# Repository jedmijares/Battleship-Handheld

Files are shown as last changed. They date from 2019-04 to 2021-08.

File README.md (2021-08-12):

# Battleship Handheld

This project was created as the final project for EE 287 (Intro to Embedded Systems), by Jed Mijares and Jacob Culler.

## YouTube Video Demo

[Watch Here](https://www.youtube.com/watch?v=jDSAx5fQOlo)

## Compiling

Battleship was written and built with Keil uVision5.

## Description and Operation

If you are not familiar with the board game Battleship, you can read about it [here.](https://en.wikipedia.org/wiki/Battleship_(game))

We implemented the game on a Texas Intrument Tiva C Series Launchpad (EK-TM4C123GXL). When booted up, a short credit message is displayed on a Nokia 5110 screen. The user may press any button to proceed to the game board. The time at which they press the button is used as a seed for a randomization function, and we use this function to randomly place a length 2, length 3, and length 4 ship on an 8x8 grid. Next, the player will use the D-pad to navigate and the select button to fire at the selected square. The game will display an X for each square with a targeted ship and a 0 for each targeted empty square. The game is completed when the player has sunken each ship. At this point, a win screen is displayed, showing the number of shots the player had to fire to complete the game. They player can hit any button to reset the game and play again.

## Explanation of Design Choices

We were attracted to using the Nokia 5110 screen, as Dr. Valvano had provided a library for it as part of his online Embedded Systems course, which we referred to often throughout this semester. We settled upon implementing Battleship after discovering that the Nokia screen flickered a lot when sprites were quickly moved across it.

We used an 8x8 grid for the board as it fit nicely on the Nokia's 48x84 pixel screen. This left enough space for 6 rows of 4 characters, which we used to display the number of shots fired, the number of successful hits, and which ships had been successfully sunk. In software, the board is a 2 dimensional array of _Square_ structs, which keep track of whether a tile has been shot and an ID for the ship that resides there (or lack thereof).

The PCB features several extraneous components. These include a terminal block for breaking out UART pins, an extra unused button, and several rows of jumper pins. These serve no purpose in the current design, but were added in case we decided to implement a feature that would require them.

## Parts List

* TM4C123G LaunchPad Evaluation Kit
* Nokia 5110 Screen Breakout Board
* Piezo Buzzer
* 10kR Resistor (5)
* Pushbutton Switch (5)

### Optional Components

* 330R Resistor (may be used to enable the backlight)
* 4-pin terminal block (breaks out the UART pins, which currently are not used)
* 10kR Resistor (for extra button that currently serves no purpose)
* Pushbutton Switch (extra button that currently serves no purpose)

## Flow Diagram

[Code Flow Diagram](https://github.com/jedmijares/EE-287-Final-Project/blob/master/Media/Code%20Block%20Diagram.pdf)

## Explanation of Major Components

The Tiva board is crucial to the project, and controls all the other components and handles the processing for the game itself.

The Tiva communicates with the Nokia 5110 screen serially and uses it to communicate all visual output.

A piezo buzzer is also implemented. Whenever a button is pressed, the SysTick timer is used to oscillate the buzzer pin for a specified number of milliseconds.

The PCB was designed in Autodesk EAGLE. Relevant design files are in the EAGLE folder.

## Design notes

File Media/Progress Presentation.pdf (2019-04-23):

# BATTLESHIP GAME

Jed Mijares

Jacob Culler

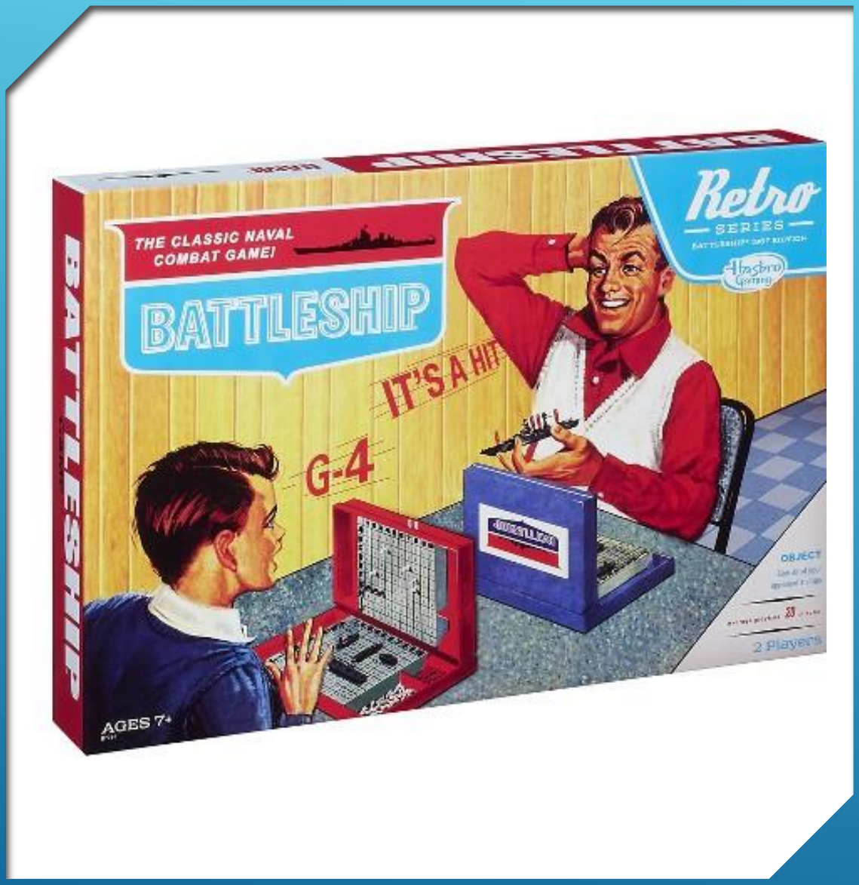
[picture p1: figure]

# INTRODUCTION / PROJECT DESCRIPTION

We are making a handheld
game that lets you play the board game battleship

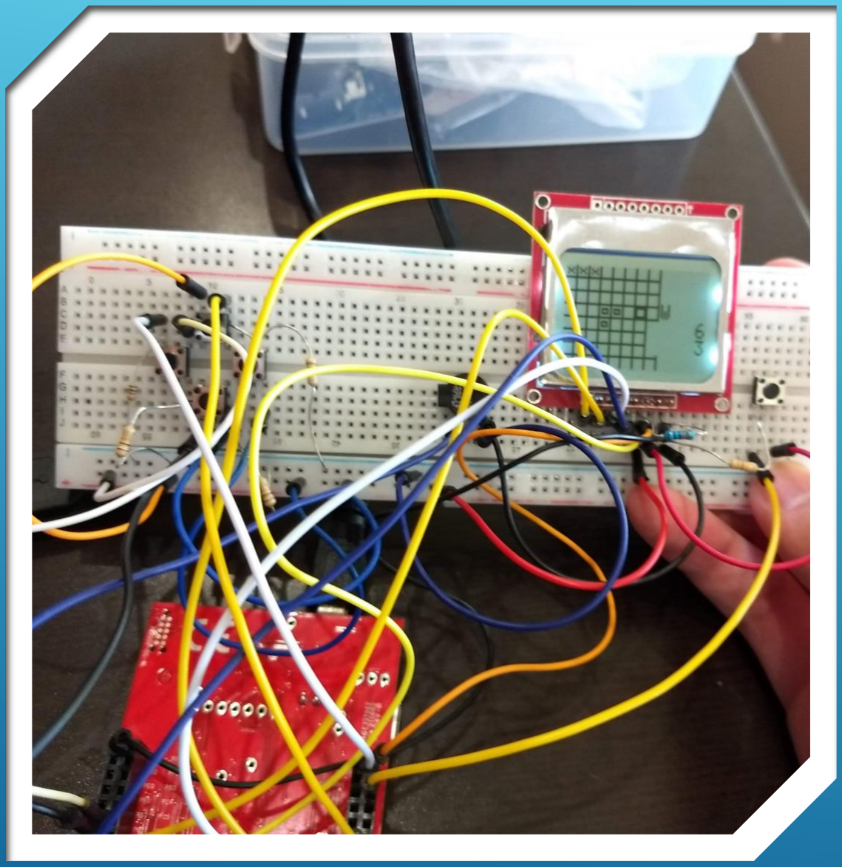
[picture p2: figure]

# CURRENT PROGRESS

- LCD Communication
- Button Integration
- Sound Output
- Basic Game Logic

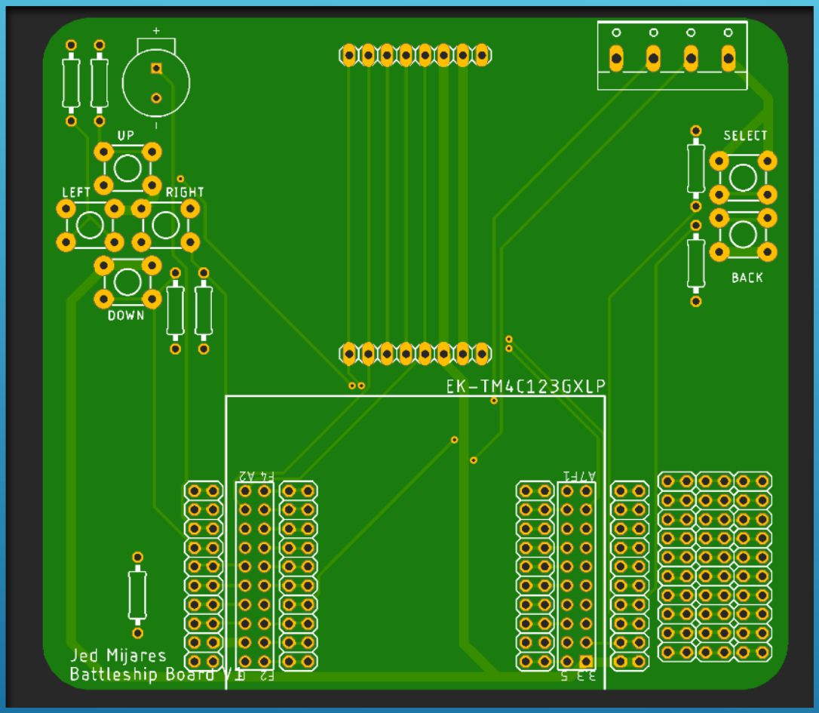
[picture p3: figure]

# REMAINING WORK

- Implement randomization
- Clean up code/formatting
- Produce video
- Print/assemble PCB
- Online scoreboard
- UART Multiplayer/computer player
- Create frame

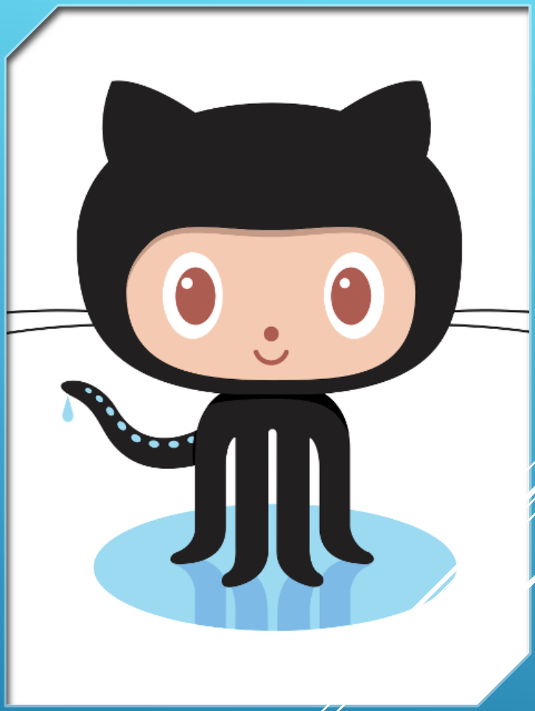
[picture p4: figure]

# DIFFICULTIES

- Learning how to use GitHub collaboratively
- LCD blur prevented us from making a more “actiony” game
- Discovered we could only print bitmaps of an even width

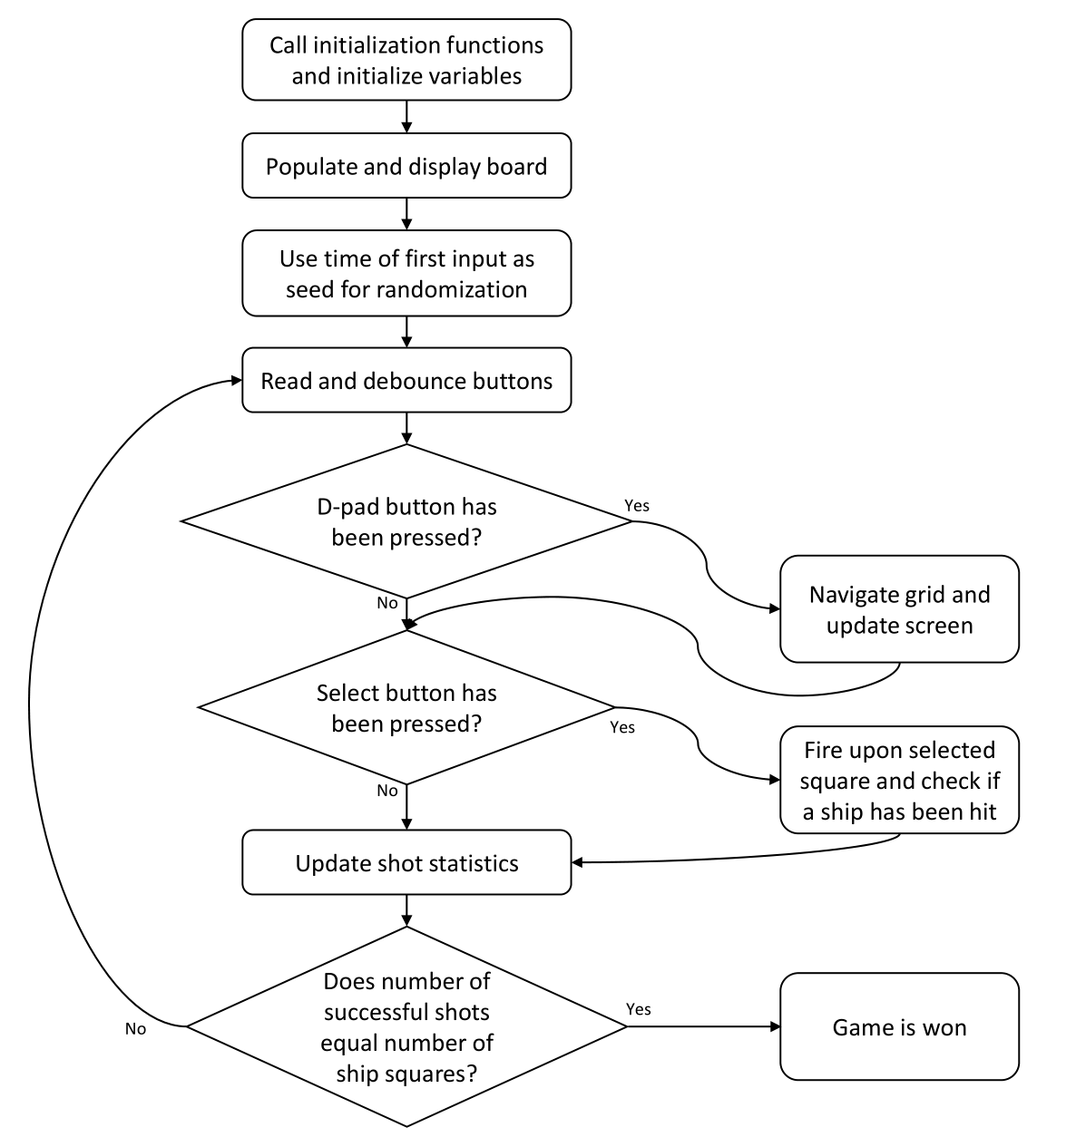
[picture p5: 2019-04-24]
Media/CodeBlockDiagram.PNG

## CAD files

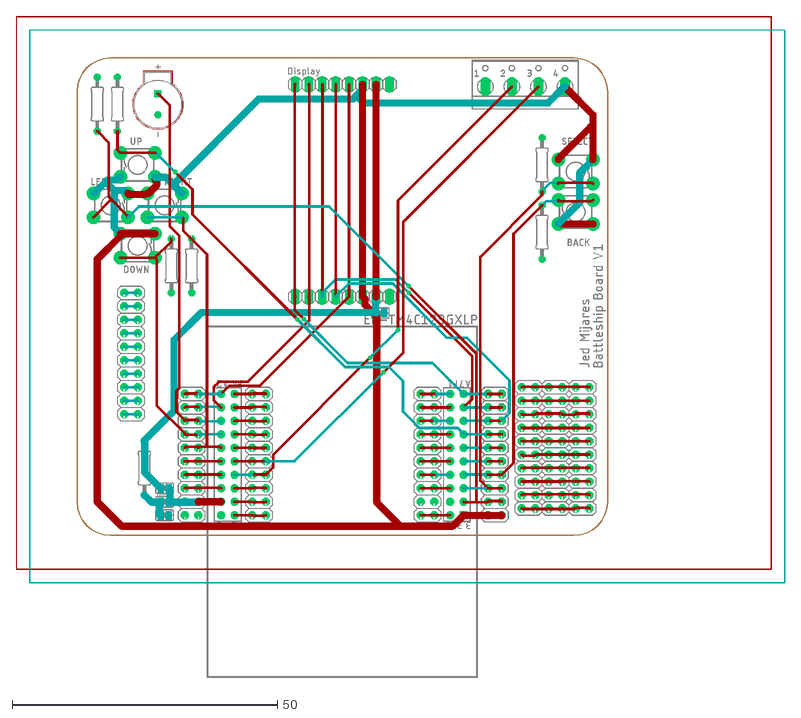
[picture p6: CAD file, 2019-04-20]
EAGLE/battleship.dxf
144.9 x 124.7

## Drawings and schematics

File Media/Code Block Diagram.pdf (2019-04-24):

EE 287

### Battleship Block Diagram

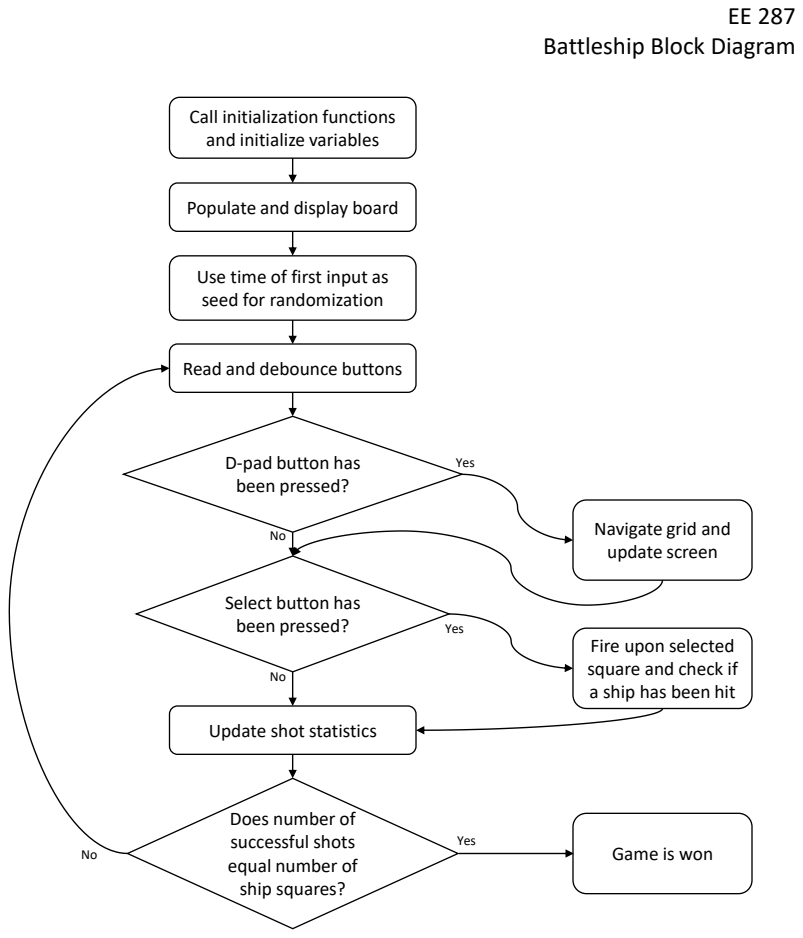
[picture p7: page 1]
Yes

Call initialization functions
and initialize variables

Populate and display board

Use time of first input as
seed for randomization

Read and debounce buttons

D-pad button has
been pressed?

Navigate grid and
update screen

Select button has

Fire upon selected
square and check if
a ship has been hit

Update shot statistics

Does number of
successful shots
equal number of
ship squares?

Game is won

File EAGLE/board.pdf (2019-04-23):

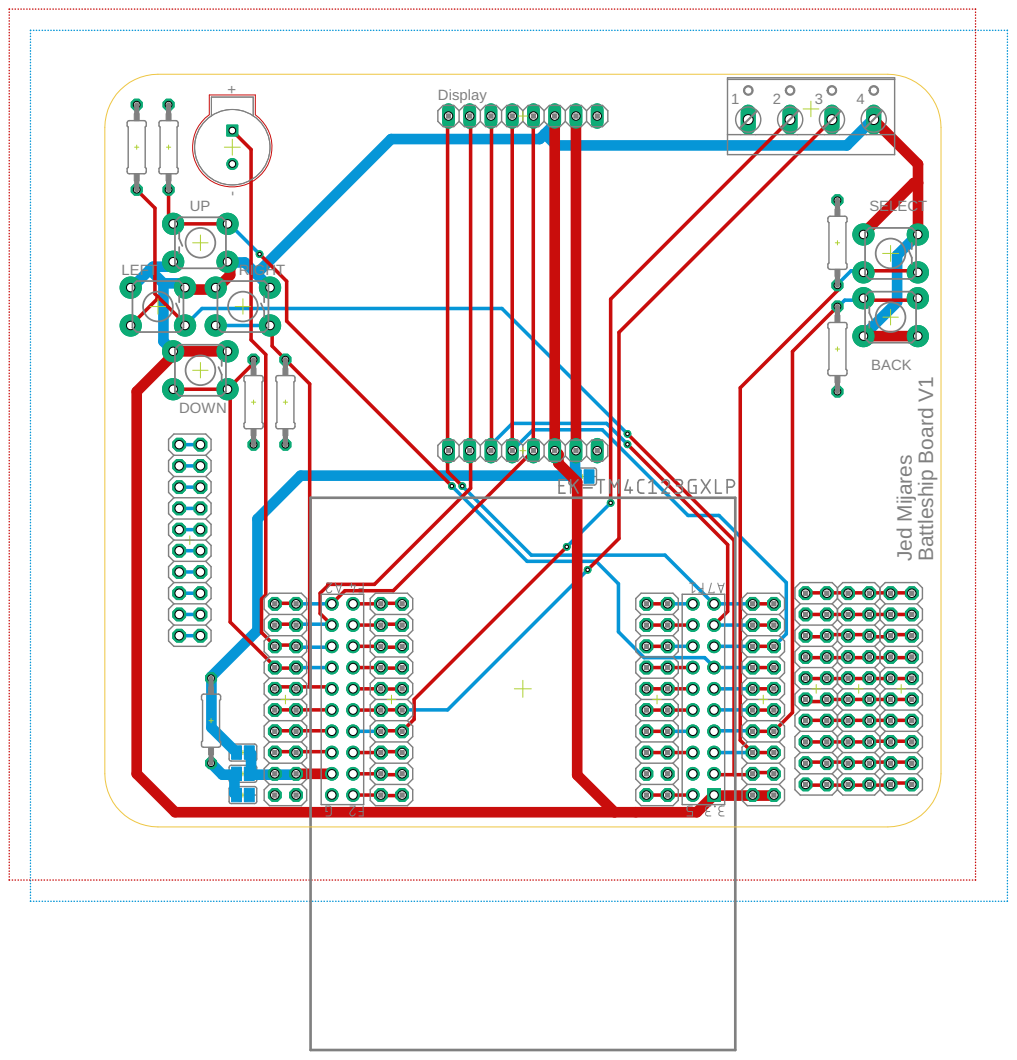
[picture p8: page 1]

Jed Mijares Battleship Board V1 + - 1 2 3 4 LEFT RIGHT DOWN UP SELECT BACK Display

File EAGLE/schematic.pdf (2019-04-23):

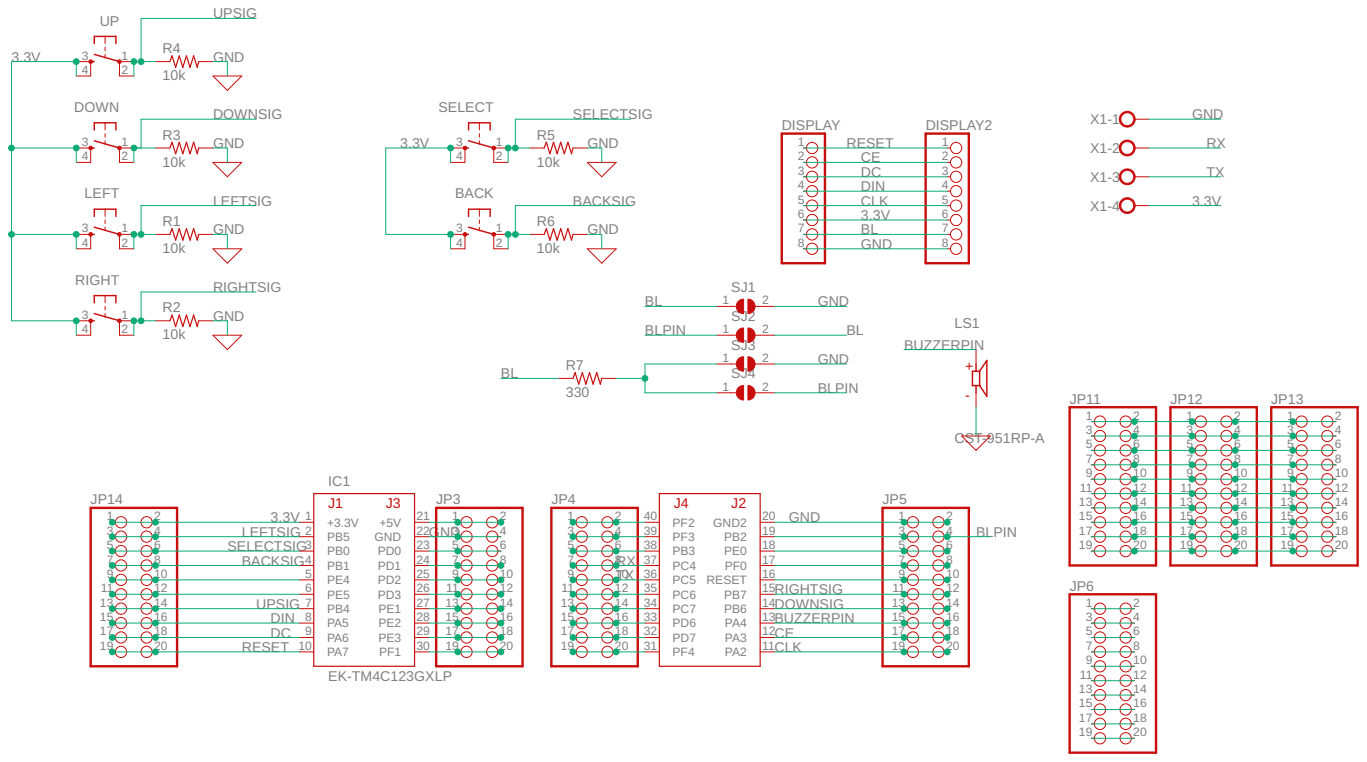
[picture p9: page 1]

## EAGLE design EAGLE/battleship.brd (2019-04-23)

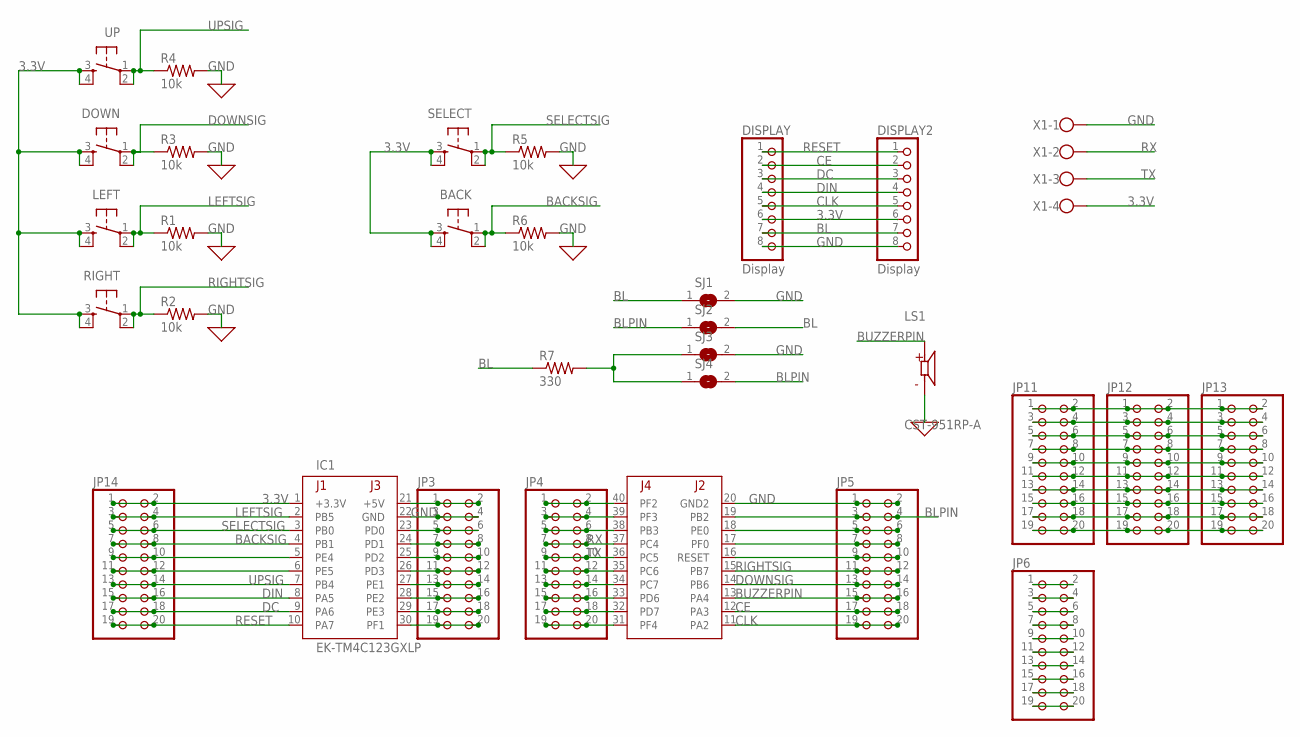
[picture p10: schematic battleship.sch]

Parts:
BACK: TAC_SWITCHPTH; TACTILE-PTH
DISPLAY, DISPLAY2: Display; 1X08
DOWN: TAC_SWITCHPTH; TACTILE-PTH
IC1: EK-TM4C123GXLP; TM4C123LAUNCHPAD
JP3, JP4, JP5, JP6, JP11, JP12, JP13, JP14: PINHD-2X10; 2X10
LEFT: TAC_SWITCHPTH; TACTILE-PTH
LS1: CST-951RP-A; CUI_CST-951RP-A
R1, R2, R3, R4, R5, R6: 10k; 0207/10
R7: 330; 0207/10
RIGHT: TAC_SWITCHPTH; TACTILE-PTH
SELECT: TAC_SWITCHPTH; TACTILE-PTH
SJ1, SJ2, SJ3, SJ4: SJ
UP: TAC_SWITCHPTH; TACTILE-PTH
X1: W237-4

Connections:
3.3V: BACK.3, BACK.4, DISPLAY.6, DISPLAY2.6, DOWN.3, DOWN.4, IC1.1 (+3.3V), JP14.1, JP14.2, LEFT.3, LEFT.4, RIGHT.3, RIGHT.4, SELECT.3, SELECT.4, UP.3, UP.4, X1.4
BACKSIG: BACK.1, BACK.2, IC1.4 (PB1), JP14.7, JP14.8, R6.1
BL: DISPLAY.7, DISPLAY2.7, R7.1, SJ1.1, SJ2.2
BLPIN: IC1.19 (PB2), JP5.3, JP5.4, SJ2.1, SJ4.2
BUZZERPIN: IC1.13 (PA4), JP5.15, JP5.16, LS1.P
CE: DISPLAY.2, DISPLAY2.2, IC1.12 (PA3), JP5.17, JP5.18
CLK: DISPLAY.5, DISPLAY2.5, IC1.11 (PA2), JP5.19, JP5.20
DC: DISPLAY.3, DISPLAY2.3, IC1.9 (PA6), JP14.17, JP14.18
DIN: DISPLAY.4, DISPLAY2.4, IC1.8 (PA5), JP14.15, JP14.16
DOWNSIG: DOWN.1, DOWN.2, IC1.14 (PB6), JP5.13, JP5.14, R3.1
GND: DISPLAY.8, DISPLAY2.8, IC1.20 (GND2), IC1.22 (GND), JP3.3, JP3.4, JP5.1, JP5.2, LS1.M, R1.2, R2.2, R3.2, R4.2, R5.2, R6.2, SJ1.2, SJ3.2, X1.1
LEFTSIG: IC1.2 (PB5), JP14.3, JP14.4, LEFT.1, LEFT.2, R1.1
unnamed: JP6.1, JP6.2
unnamed: JP6.3, JP6.4
unnamed: JP6.5, JP6.6
unnamed: JP6.7, JP6.8
unnamed: JP6.9, JP6.10
unnamed: R7.2, SJ3.1, SJ4.1
unnamed: JP6.11, JP6.12
unnamed: JP6.13, JP6.14
unnamed: JP6.15, JP6.16
unnamed: JP6.19, JP6.20
unnamed: JP6.17, JP6.18
unnamed: IC1.5 (PE4), JP14.9, JP14.10
unnamed: IC1.21 (+5V), JP3.1, JP3.2
unnamed: IC1.23 (PD0), JP3.5, JP3.6
unnamed: IC1.24 (PD1), JP3.7, JP3.8
unnamed: IC1.16 (RESET), JP5.9, JP5.10
unnamed: IC1.17 (PF0), JP5.7, JP5.8
unnamed: IC1.18 (PE0), JP5.5, JP5.6
unnamed: IC1.28 (PE2), JP3.15, JP3.16
unnamed: IC1.29 (PE3), JP3.17, JP3.18
unnamed: IC1.30 (PF1), JP3.19, JP3.20
unnamed: IC1.31 (PF4), JP4.19, JP4.20
unnamed: IC1.32 (PD7), JP4.17, JP4.18
unnamed: IC1.26 (PD3), JP3.11, JP3.12
unnamed: IC1.25 (PD2), JP3.9, JP3.10
unnamed: JP11.3, JP11.4, JP12.3, JP12.4, JP13.3, JP13.4
unnamed: JP11.7, JP11.8, JP12.7, JP12.8, JP13.7, JP13.8
unnamed: IC1.33 (PD6), JP4.15, JP4.16
unnamed: IC1.34 (PC7), JP4.13, JP4.14
unnamed: JP11.11, JP11.12, JP12.11, JP12.12, JP13.11, JP13.12
unnamed: IC1.35 (PC6), JP4.11, JP4.12
unnamed: JP11.15, JP11.16, JP12.15, JP12.16, JP13.15, JP13.16
unnamed: JP11.17, JP11.18, JP12.17, JP12.18, JP13.17, JP13.18
unnamed: JP11.19, JP11.20, JP12.19, JP12.20, JP13.19, JP13.20
unnamed: IC1.38 (PB3), JP4.5, JP4.6
unnamed: IC1.39 (PF3), JP4.3, JP4.4
unnamed: IC1.40 (PF2), JP4.1, JP4.2
unnamed: IC1.6 (PE5), JP14.11, JP14.12
unnamed: IC1.27 (PE1), JP3.13, JP3.14
unnamed: JP11.1, JP11.2, JP12.1, JP12.2, JP13.1, JP13.2
unnamed: JP11.5, JP11.6, JP12.5, JP12.6, JP13.5, JP13.6
unnamed: JP11.9, JP11.10, JP12.9, JP12.10, JP13.9, JP13.10
unnamed: JP11.13, JP11.14, JP12.13, JP12.14, JP13.13, JP13.14
RESET: DISPLAY.1, DISPLAY2.1, IC1.10 (PA7), JP14.19, JP14.20
RIGHTSIG: IC1.15 (PB7), JP5.11, JP5.12, R2.1, RIGHT.1, RIGHT.2
RX: IC1.37 (PC4), JP4.7, JP4.8, X1.2
SELECTSIG: IC1.3 (PB0), JP14.5, JP14.6, R5.1, SELECT.1, SELECT.2
TX: IC1.36 (PC5), JP4.9, JP4.10, X1.3
UPSIG: IC1.7 (PB4), JP14.13, JP14.14, R4.1, UP.1, UP.2

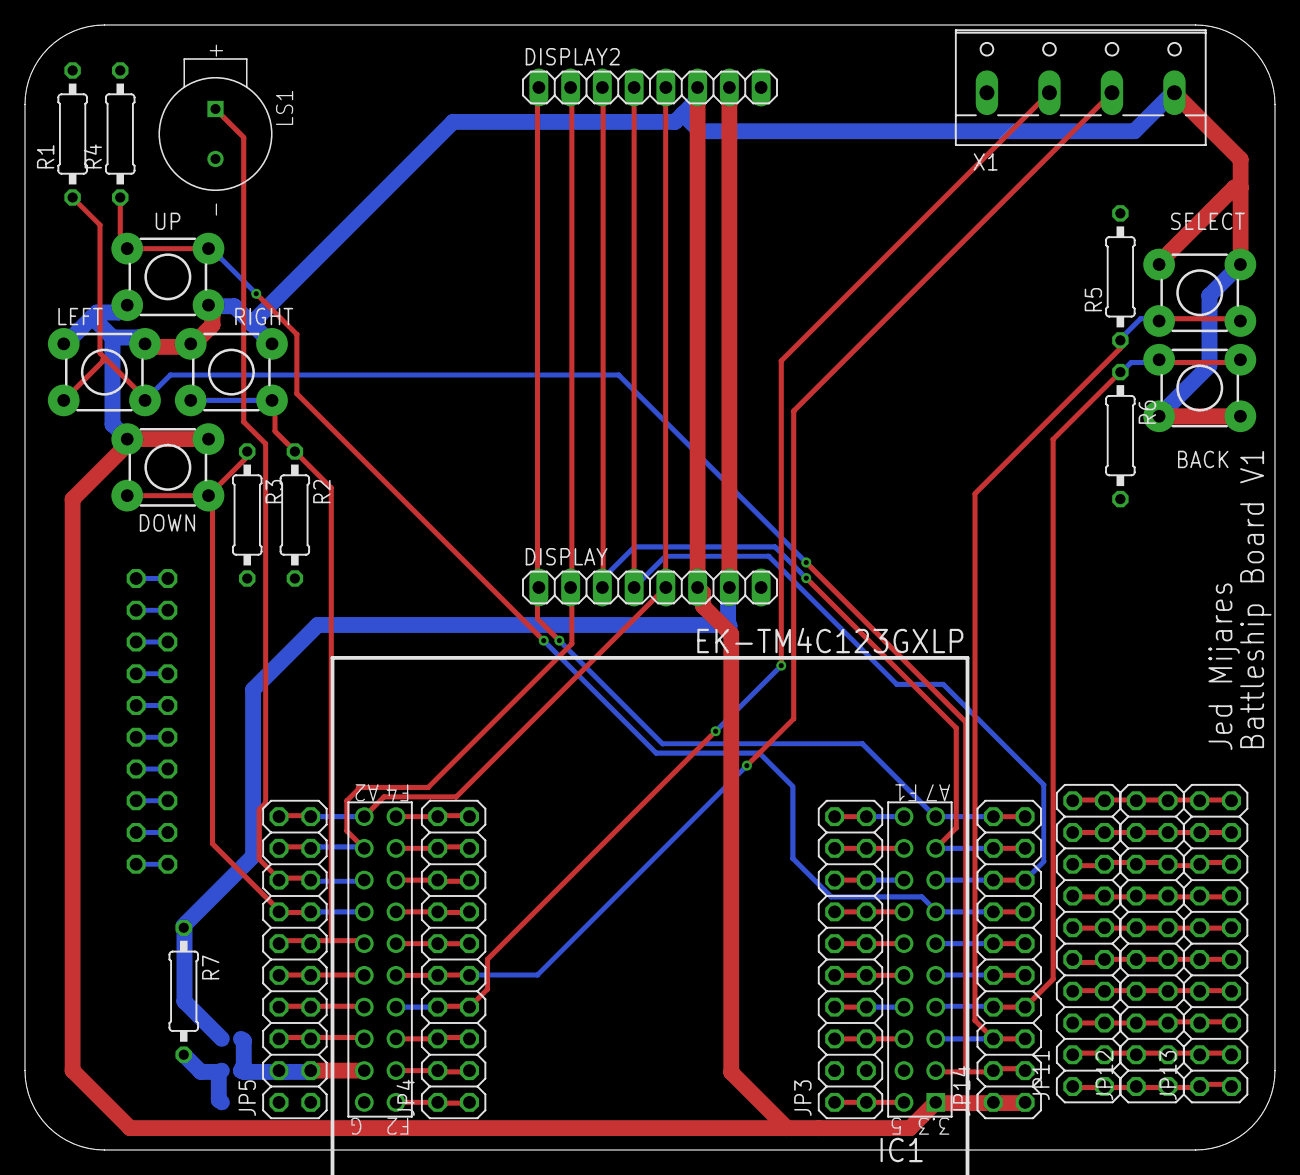
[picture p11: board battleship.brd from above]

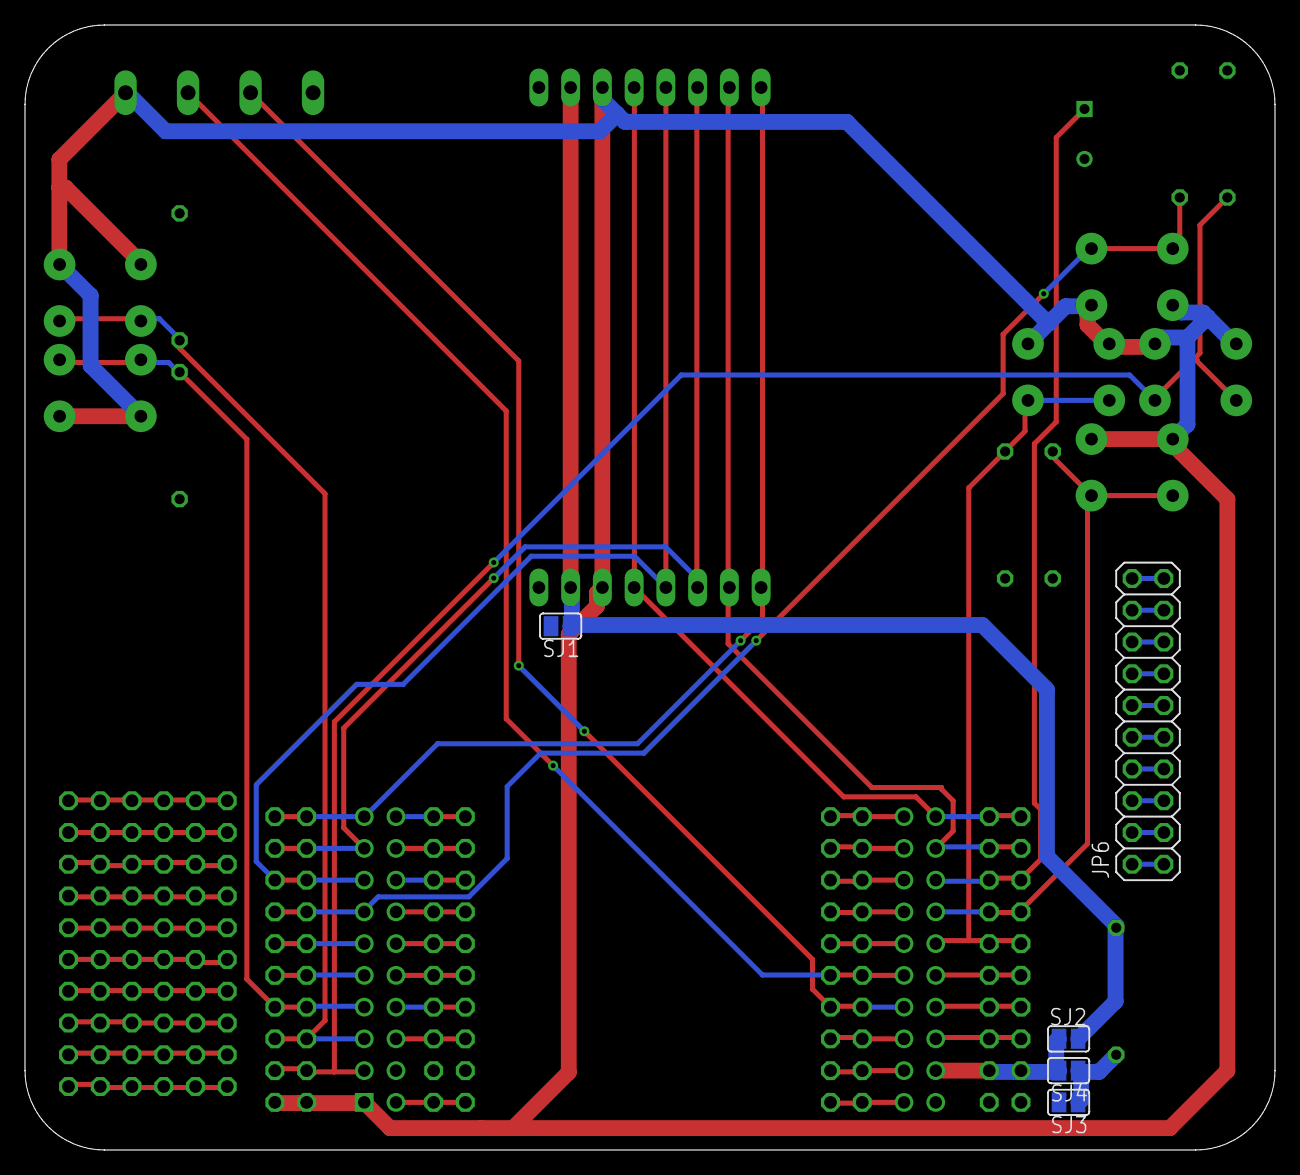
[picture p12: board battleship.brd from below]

Board: 2 copper layers, 100.0 x 90.0 mm, 30 parts (5 on the bottom side), 61 nets.

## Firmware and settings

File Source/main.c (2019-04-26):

// main file for EE 287 final project
// By Jed Mijares and Jacob Culler

#include "Nokia5110.h"
#include "PLL.h"
#include "Ports.h"
#include "SysTick.h"
#include "tm4c123gh6pm.h"
#include "structs.h"
#include "printMatrix.h"
#include "random.h"
#include <stdbool.h>

struct Square board[8][8];
short xCursor = 0;
short yCursor = 0;


void checkBounds(short *x , short *y){
	if(*x > 7)
		*x = 7;
	if(*x < 0)
		*x = 0;
	if(*y < 0)
		*y = 0;
	if(*y > 7)
		*y = 7;
}

void fire(){
	checkBounds(&xCursor, &yCursor);
	board[xCursor][yCursor].isHit = 1;
	select(board, xCursor, yCursor);
}

void xPlus(){
	xCursor++;
	checkBounds(&xCursor, &yCursor);
	select(board, xCursor, yCursor);
}
void yPlus(){
	yCursor++;
	checkBounds(&xCursor, &yCursor);
	select(board, xCursor, yCursor);
}
void xMinus(){
	xCursor--;
	checkBounds(&xCursor, &yCursor);
	select(board, xCursor, yCursor);
}
void yMinus(){
	yCursor--;
	checkBounds(&xCursor, &yCursor);
	select(board, xCursor, yCursor);
}

int main(void)
{	
	int shotsFired = 0;
	int goodShots = 0; // number of successful hits against ships
	short buttonState; // actually used to check input
	short oldReading = 0x11; // previous reading of buttons
	unsigned long lastDebounceTime = 0; 
	unsigned long debounceDelay = 50; // time to wait before more button input
	const short SHOTSNEEDED = 9; // shots needed to win game
	short reading; // reading of buttons
	//unsigned long startTime; // used to prevent accidental input at start of game
	
	PLL_Init(); // set clock to 80 MHz
	Ports_Init();
	SysTick_Init(80000); // interrupt every 80,000 cycles (1 ms at 80 MHz)
	Nokia5110_Init();
	
	struct Ship ships[3];
	ships[0].length = 2;
	ships[1].length = 3;
	ships[2].length = 4;
	ships[0].ID = 0;
	ships[1].ID = 1;
	ships[2].ID = 2;
	
startGame:
	shotsFired = 0;
	goodShots = 0;
	ships[0].hits = 0;
	ships[1].hits = 0;
	ships[2].hits = 0;
  delay1ms(500);
	
	
	for(short i = 0; i < 8; i++){  // reset board
		for(short j = 0; j < 8; j++){
			board[i][j].isHit = 0;
			board[i][j].shipID = -1;
		}
	}
	
	Nokia5110_Clear();
	Nokia5110_ClearBuffer();
	Nokia5110_SetCursor(1,1);
	Nokia5110_OutString("Jed");
	Nokia5110_SetCursor(2,2);
	Nokia5110_OutString("M.");
	
	Nokia5110_SetCursor(6,1);
	Nokia5110_OutString("Jacob");
	Nokia5110_SetCursor(8,2);
	Nokia5110_OutString("C.");
	
	Nokia5110_SetCursor(3,3);
	Nokia5110_OutString("Present");
	Nokia5110_SetCursor(1,4);
	Nokia5110_OutString("Battleship");
	delay1ms(500);
//oldReading = readBButtons();
	while(!readBButtons()) {} //oldReading) oldReading = readBButtons();
	Nokia5110_Clear();
	
	Random_Init(NVIC_ST_CURRENT_R); // random seed depending on when user presses button to start
		
	randomPlaceShip(ships[0], board);
	randomPlaceShip(ships[1], board);
	randomPlaceShip(ships[2], board);
	printGrid();
	print(board);
	select(board, xCursor, yCursor);
	Nokia5110_DisplayBuffer();
		
	ships[1].hits = 0; // for some reason this is necessary????????
										 // like, this is seriously bizzare. For some reason ships[1].hits gets initialized to 0x2000 in the randomPlaceShip function, and it's the only one to do so
	lastDebounceTime = millis();
	
	while(1) //startTime <= (millis()-10))// - 150)) // couldn't get this to work for whatever reason
	{
		reading = readBButtons(); // read value of buttons
		if(reading != oldReading ) lastDebounceTime = millis(); // if reading does not match last value, we're still bouncing
		if((millis() - lastDebounceTime) > debounceDelay) // if the time since the last bounce is greater than the delay, step in
		{
			if (reading != buttonState) // if the reading does not match what the computer thinks the button was last, step in
			{
				buttonState = reading;
				if(rightPressed() && xCursor < 7)
				{
					xPlus();
					Nokia5110_DisplayBuffer();
					beep(50);
				}
				if(downPressed() && yCursor < 7)
				{
					yPlus();
					Nokia5110_DisplayBuffer();
					beep(50);
				}
				if(leftPressed() && xCursor >0)
				{
					xMinus();
					Nokia5110_DisplayBuffer();
					beep(50);
				}
				if(upPressed() && yCursor > 0)
				{
					yMinus();
					Nokia5110_DisplayBuffer();
					beep(50);
				}
				if(selectPressed() && board[xCursor][yCursor].isHit == 0) 
				{
					if(board[xCursor][yCursor].isHit == 0 & board[xCursor][yCursor].shipID >= 0) 
					{
						goodShots++;
						ships[board[xCursor][yCursor].shipID].hits++;
						
					}
					fire();
					shotsFired++;
					Nokia5110_DisplayBuffer();
					beep(50);
				}
			}
		}
		oldReading = reading;
		
		Nokia5110_SetCursor(8,0);
		Nokia5110_OutString("Shot");
		Nokia5110_SetCursor(8,1);
		Nokia5110_OutUDec2(shotsFired); // modified version of OutUDec that doesn't add space beforehand
		
		Nokia5110_SetCursor(8,2);
		Nokia5110_OutString("Hits");
		Nokia5110_SetCursor(8,3);
		Nokia5110_OutUDec2(goodShots);
		
		Nokia5110_SetCursor(8,4);
		Nokia5110_OutString("Sunk");
		if(ships[1].length <= ships[1].hits)
		{
			Nokia5110_SetCursor(9,5);
			Nokia5110_OutString("3");
		}
		if(ships[0].length == ships[0].hits)
		{
			Nokia5110_SetCursor(8,5);
			Nokia5110_OutChar('2');
		}
		if(ships[2].length == ships[2].hits)
		{
			Nokia5110_SetCursor(10,5);
			Nokia5110_OutChar('4');
		}
		
		if(goodShots >= SHOTSNEEDED)
		{
			Nokia5110_Clear();
			delay1ms(500);
			while(!readBButtons())
			{
				winscreen(shotsFired);
				Nokia5110_DisplayBuffer();
				Nokia5110_SetCursor(5,5);
				Nokia5110_OutUDec2(shotsFired);	
			}
			beep(50);
			goto startGame;
		}
	}
}
 

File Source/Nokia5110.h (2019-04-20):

#ifndef _Nokia5110_h
#define _Nokia5110_h

// Nokia5110.h
// Runs on LM4F120/TM4C123
// Use SSI0 to send an 8-bit code to the Nokia5110 48x84
// pixel LCD to display text, images, or other information.
// Daniel Valvano
// September 16, 2013

// Font table, initialization, and other functions based
// off of Nokia_5110_Example from Spark Fun:
// 7-17-2011
// Spark Fun Electronics 2011
// Nathan Seidle
// http://dlnmh9ip6v2uc.cloudfront.net/datasheets/LCD/Monochrome/Nokia_5110_Example.pde

/* This example accompanies the book
   "Embedded Systems: Introduction to ARM Cortex M Microcontrollers",
   ISBN: 978-1469998749, Jonathan Valvano, copyright (c) 2014

 Copyright 2014 by Jonathan W. Valvano, valvano@mail.utexas.edu
    You may use, edit, run or distribute this file
    as long as the above copyright notice remains
 THIS SOFTWARE IS PROVIDED "AS IS".  NO WARRANTIES, WHETHER EXPRESS, IMPLIED
 OR STATUTORY, INCLUDING, BUT NOT LIMITED TO, IMPLIED WARRANTIES OF
 MERCHANTABILITY AND FITNESS FOR A PARTICULAR PURPOSE APPLY TO THIS SOFTWARE.
 VALVANO SHALL NOT, IN ANY CIRCUMSTANCES, BE LIABLE FOR SPECIAL, INCIDENTAL,
 OR CONSEQUENTIAL DAMAGES, FOR ANY REASON WHATSOEVER.
 For more information about my classes, my research, and my books, see
 http://users.ece.utexas.edu/~valvano/
 */

// Blue Nokia 5110
// ---------------
// Signal        (Nokia 5110) LaunchPad pin
// Reset         (RST, pin 1) connected to PA7
// SSI0Fss       (CE,  pin 2) connected to PA3
// Data/Command  (DC,  pin 3) connected to PA6
// SSI0Tx        (Din, pin 4) connected to PA5
// SSI0Clk       (Clk, pin 5) connected to PA2
// 3.3V          (Vcc, pin 6) power
// back light    (BL,  pin 7) not connected, consists of 4 white LEDs which draw ~80mA total
// Ground        (Gnd, pin 8) ground

// Red SparkFun Nokia 5110 (LCD-10168)
// -----------------------------------
// Signal        (Nokia 5110) LaunchPad pin
// 3.3V          (VCC, pin 1) power
// Ground        (GND, pin 2) ground
// SSI0Fss       (SCE, pin 3) connected to PA3
// Reset         (RST, pin 4) connected to PA7
// Data/Command  (D/C, pin 5) connected to PA6
// SSI0Tx        (DN,  pin 6) connected to PA5
// SSI0Clk       (SCLK, pin 7) connected to PA2
// back light    (LED, pin 8) not connected, consists of 4 white LEDs which draw ~80mA total

// Maximum dimensions of the LCD, although the pixels are
// numbered from zero to (MAX-1).  Address may automatically
// be incremented after each transmission.
#define MAX_X                   84
#define MAX_Y                   48
// *************************** Screen dimensions ***************************
#define SCREENW     84
#define SCREENH     48

// Contrast value 0xB1 looks good on red SparkFun
// and 0xB8 looks good on blue Nokia 5110.
// Adjust this from 0xA0 (lighter) to 0xCF (darker) for your display.
#define CONTRAST                0xBF

// This table contains the hex values that represent pixels
// for a font that is 5 pixels wide and 8 pixels high
static const char ASCII[][5] = {
  {0x00, 0x00, 0x00, 0x00, 0x00} // 20
  ,{0x00, 0x00, 0x5f, 0x00, 0x00} // 21 !
  ,{0x00, 0x07, 0x00, 0x07, 0x00} // 22 "
  ,{0x14, 0x7f, 0x14, 0x7f, 0x14} // 23 #
  ,{0x24, 0x2a, 0x7f, 0x2a, 0x12} // 24 $
  ,{0x23, 0x13, 0x08, 0x64, 0x62} // 25 %
  ,{0x36, 0x49, 0x55, 0x22, 0x50} // 26 &
  ,{0x00, 0x05, 0x03, 0x00, 0x00} // 27 '
  ,{0x00, 0x1c, 0x22, 0x41, 0x00} // 28 (
  ,{0x00, 0x41, 0x22, 0x1c, 0x00} // 29 )
  ,{0x14, 0x08, 0x3e, 0x08, 0x14} // 2a *
  ,{0x08, 0x08, 0x3e, 0x08, 0x08} // 2b +
  ,{0x00, 0x50, 0x30, 0x00, 0x00} // 2c ,
  ,{0x08, 0x08, 0x08, 0x08, 0x08} // 2d -
  ,{0x00, 0x60, 0x60, 0x00, 0x00} // 2e .
  ,{0x20, 0x10, 0x08, 0x04, 0x02} // 2f /
  ,{0x3e, 0x51, 0x49, 0x45, 0x3e} // 30 0
  ,{0x00, 0x42, 0x7f, 0x40, 0x00} // 31 1
  ,{0x42, 0x61, 0x51, 0x49, 0x46} // 32 2
  ,{0x21, 0x41, 0x45, 0x4b, 0x31} // 33 3
  ,{0x18, 0x14, 0x12, 0x7f, 0x10} // 34 4
  ,{0x27, 0x45, 0x45, 0x45, 0x39} // 35 5
  ,{0x3c, 0x4a, 0x49, 0x49, 0x30} // 36 6
  ,{0x01, 0x71, 0x09, 0x05, 0x03} // 37 7
  ,{0x36, 0x49, 0x49, 0x49, 0x36} // 38 8
  ,{0x06, 0x49, 0x49, 0x29, 0x1e} // 39 9
  ,{0x00, 0x36, 0x36, 0x00, 0x00} // 3a :
  ,{0x00, 0x56, 0x36, 0x00, 0x00} // 3b ;
  ,{0x08, 0x14, 0x22, 0x41, 0x00} // 3c <
  ,{0x14, 0x14, 0x14, 0x14, 0x14} // 3d =
  ,{0x00, 0x41, 0x22, 0x14, 0x08} // 3e >
  ,{0x02, 0x01, 0x51, 0x09, 0x06} // 3f ?
  ,{0x32, 0x49, 0x79, 0x41, 0x3e} // 40 @
  ,{0x7e, 0x11, 0x11, 0x11, 0x7e} // 41 A
  ,{0x7f, 0x49, 0x49, 0x49, 0x36} // 42 B
  ,{0x3e, 0x41, 0x41, 0x41, 0x22} // 43 C
  ,{0x7f, 0x41, 0x41, 0x22, 0x1c} // 44 D
  ,{0x7f, 0x49, 0x49, 0x49, 0x41} // 45 E
  ,{0x7f, 0x09, 0x09, 0x09, 0x01} // 46 F
  ,{0x3e, 0x41, 0x49, 0x49, 0x7a} // 47 G
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
//  ,{0x78, 0x46, 0x41, 0x46, 0x78} // 7f DEL
  ,{0x1f, 0x24, 0x7c, 0x24, 0x1f} // 7f UT sign
};

//********Nokia5110_Init*****************
// Initialize Nokia 5110 48x84 LCD by sending the proper
// commands to the PCD8544 driver.  One new feature of the
// LM4F120 is that its SSIs can get their baud clock from
// either the system clock or from the 16 MHz precision
// internal oscillator.  If the system clock is faster than
// 50 MHz, the SSI baud clock will be faster than the 4 MHz
// maximum of the Nokia 5110.
// inputs: none
// outputs: none
// assumes: system clock rate of 50 MHz or less
void Nokia5110_Init(void);

//********Nokia5110_OutChar*****************
// Print a character to the Nokia 5110 48x84 LCD.  The
// character will be printed at the current cursor position,
// the cursor will automatically be updated, and it will
// wrap to the next row or back to the top if necessary.
// One blank column of pixels will be printed on either side
// of the character for readability.  Since characters are 8
// pixels tall and 5 pixels wide, 12 characters fit per row,
// and there are six rows.
// inputs: data  character to print
// outputs: none
// assumes: LCD is in default horizontal addressing mode (V = 0)
void Nokia5110_OutChar(unsigned char data);

//********Nokia5110_OutString*****************
// Print a string of characters to the Nokia 5110 48x84 LCD.
// The string will automatically wrap, so padding spaces may
// be needed to make the output look optimal.
// inputs: ptr  pointer to NULL-terminated ASCII string
// outputs: none
// assumes: LCD is in default horizontal addressing mode (V = 0)
void Nokia5110_OutString(char *ptr);

//********Nokia5110_OutUDec*****************
// Output a 16-bit number in unsigned decimal format with a
// fixed size of five right-justified digits of output.
// Inputs: n  16-bit unsigned number
// Outputs: none
// assumes: LCD is in default horizontal addressing mode (V = 0)
void Nokia5110_OutUDec(unsigned short n);
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

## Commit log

2019-04-05 lcd and button demo
2019-04-06 implemented SysTick interrupts
2019-04-06 added button debounce demo with SysTick interrupts
2019-04-07 Revert "Update main.c"
    This reverts commit ba1d74087023149133f328636cbdf123494b8bd7, reversing
    changes made to bf83926d6c4e6ccff65b453e9a03c15814366846.
    [main.c]
2019-04-07 Revert "Revert "Update main.c""
    This reverts commit 42dc9f1fc80e100358e0df1b27d34402bff489e0.
    [main.c]
2019-04-07 tried to fix stuff
    [Nokia5110.h, main.c]
2019-04-07 hit worksish
    2 button hit works if you can click both fast enough
2019-04-08 blink and buttons in systick
2019-04-08 got buttons working
2019-04-10 added external button functionality
2019-04-10 added tiva pcb library
2019-04-10 added EAGLE files
    [battleship.brd, battleship.sch]
2019-04-10 update eagle files
    [battleship.brd, battleship.sch]
2019-04-10 finished board
    [battleship.brd, battleship.sch]
2019-04-10 added ground vias
    [battleship.brd]
2019-04-10 minor board changes
    [battleship.brd]
2019-04-11 edit boards
    [battleship.brd, battleship.sch]
2019-04-12 reduced PCB size
    [battleship.brd, battleship.sch]
2019-04-16 added board dxf
    [battleship.dxf]
2019-04-17 update board and dxf
    [battleship.brd, battleship.dxf, battleship.sch]
2019-04-17 add dxf
    [battleship.dxf]
2019-04-23 minor board updates
    [battleship.brd, battleship.sch]
2019-04-23 tried to prevent accidental input at start
    [main.c]
2019-04-24 added win screen function to printMatrix.h
